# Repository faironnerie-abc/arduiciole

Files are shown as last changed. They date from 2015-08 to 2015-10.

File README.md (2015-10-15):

# What is the "arduiciole" project ?

We try to create some electronic devices, with the ability to flash with an high power led. 
These devices will spread a signal using XBee network, and try to reproduce the 
synchronization phenomena we can observe with fireflies. "arduiciole" is the melt of 
"arduino" and "luciole" (firefly in french).

Each of our arduiciole is tied up to an hellium balloon. We will try to produce between 10 
and 30 of them, for a national science event called "Fête de la science". This show will 
take place in the university library of Le Havre (76, France).

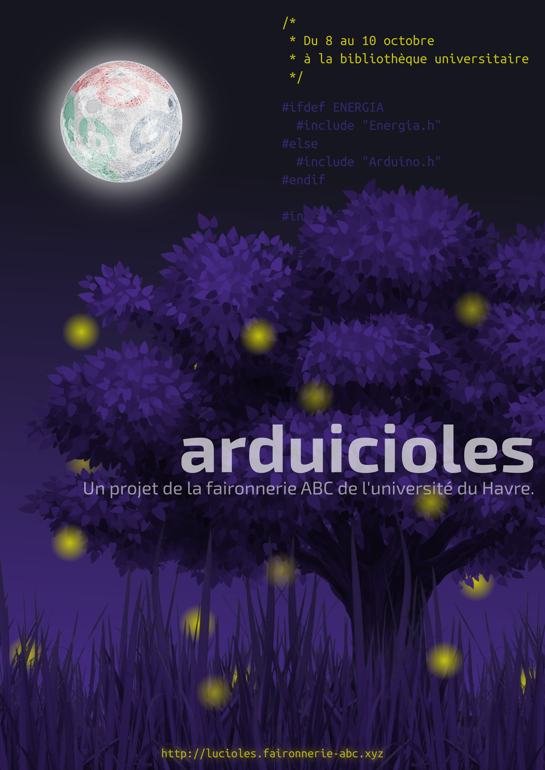
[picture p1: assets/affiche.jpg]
arduiciole case design


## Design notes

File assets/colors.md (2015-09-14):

# Couleurs

* Violet   : #482c8b
* Jaune    : #402c8c
* Fond     : dégradé linéaire, #222222 -> #482c8b
* Lucioles : dégradé radial de l'opacité, #c4c20d
* Textes :
  - Titre               : #efefef
  - Mise en valeur      : #c4c20d
  - Texte de décoration : #402c8c

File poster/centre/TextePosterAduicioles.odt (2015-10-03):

Partagez notre rêve

Nous vous proposons un voyage immobile dans l'atrium de la bibliothèque peuplé de ballons auxquels nos arduicioles sont accrochées. Avec un peu de rêve vous voilà transporté en pleine mangrove où des êtres bizarres rythment le temps avec leurs flashs. Imaginez des arbres de 10 à 12 mètres de hauteur, aux feuillages denses formés de petites feuilles ovales, portant chacune une luciole, toutes les lucioles émettant leur lumière au rythme de trois éclairs toutes les deux secondes, dans un synchronisme parfait, l'obscurité étant totale entre les éclairs. Nous vous invitons de l’autre côté du miroir.

Arduicioles : Petites lucioles électroniques mâles tentant d’échapper à la gravité accrochées à leur ballon, fabriquées à partir de contrôleurs électroniques arduinos couplés à des leds. Ces créatures artificielles sont capables de clignoter en rythme et de se synchroniser toutes ensemble.

Comportement d'une arduiciole :

Chaque luciole va avoir une horloge cyclique et émettre un flash pendant une certaine durée (durée_flash). Après chaque flash il y a un temps de latence pendant lesquelles les lucioles reconstituent les molécules (durée_charge). Chaque luciole perçoit un voisinage, lorsque le nombre de lucioles allumées est supérieur à un seuil et que la période de latence est finie, la luciole tente de se synchroniser en émettant également un flash (horloge:= 0).

Paramètres globaux :

// Même période pour tous

période

// La luciole émet un flash quand son horloge individuelle

// est entre 0 et durée_flash - 1

durée_flash

// Le temps minimum entre 2 flashs

durée_charge

// Nombre de voisins devant être allumés pour déclencher un flash

seuil

//Programme de chaque luciole :

// initialisation aléatoire de l’horloge individuelle

horloge := random(période)

répéter à l'infini {

horloge := horloge + 1

si horloge = période

horloge := 0

si (horloge > durée_flash + durée_charge) et (nombre_voisins_allumés() > seuil)

horloge := 0

si horloge = 0

flash()

si horloge = durée_flash

arrêter_flash()}

}

Dissection d'une arduiciole

Photos

Cycle des arduicioles

ToDo

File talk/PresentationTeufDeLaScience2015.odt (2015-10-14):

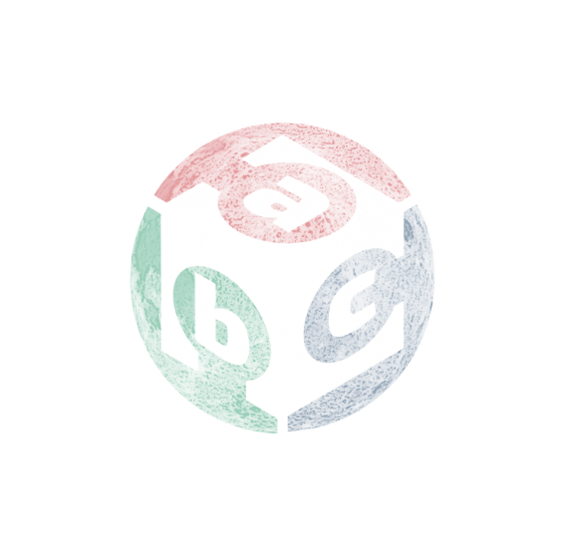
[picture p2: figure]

Arduiciole

Mesdames, messieurs, chers collègues, merci de me donner la parole pour vous présenter la faironnerie ABC et ses arduicioles dans le cadre de la fête de la science. Mais avant de faire un peu de science je vous propose de contextualiser un peu les choses. Ma présentation va se dérouler en 3 temps :

1. Fablab hackerspace et faironnerie
2. Synchronisation
3. Le projet arduiciole

# Fablab hackerspace et faironnerie

## Tiers-lieux

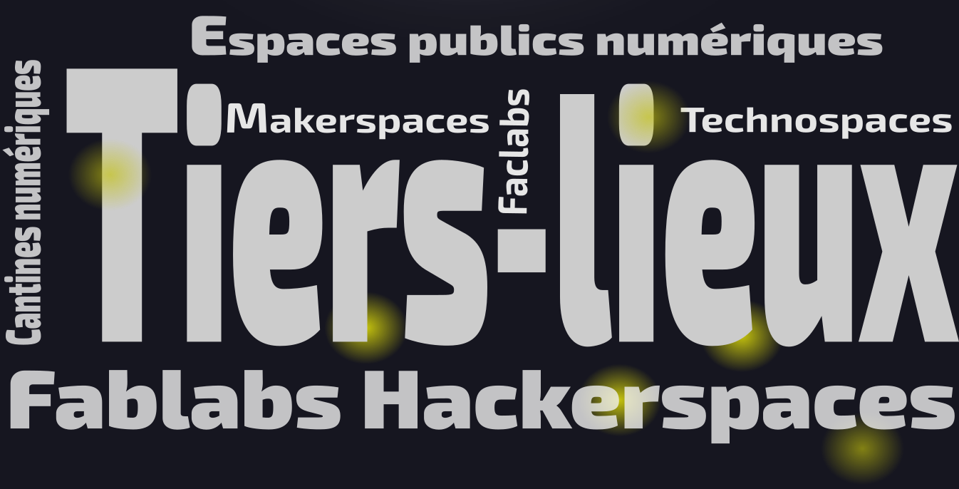
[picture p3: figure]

La novlangue a encore frappé avec ses fablabs, faclabs, techno-spaces, makerspaces et autres hackerspaces ou pour faire plus français les cantines numériques et plus largement les espaces publics numériques. Que ce cache-t-il derrière ces vocables ?

Une réalité contrastée mais avec de nombreux points communs et des objectifs souvent différents. Les différences traduisant souvent des cultures et des origines diverses. Je vous encourage d’ailleurs à ce sujet à aller écouter Michel Lallemand le lundi 1er février à l’UH dans le cadre de l’université populaire sur l’âge du « faire ».

Ces ateliers de fabrication numérique sont souvent décrits comme des tiers-lieux et par l’environnement qu’ils proposent, je ne vais pas déroger à la règle même si cela ne me semble pas le plus important/innovant, mais je reviendrai sur cela dans un second temps.

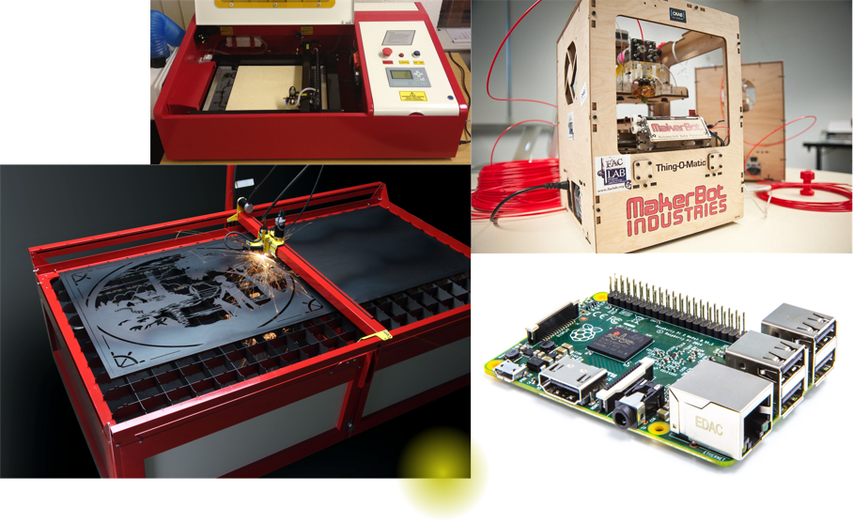
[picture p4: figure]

Ce sont des plate-formes ouvertes de création et de prototypage d’objets physiques, « intelligents » ou non. Elles s’adressent aux entrepreneurs qui veulent passer plus vite du concept au prototype ; aux designers et aux artistes ; aux étudiants désireux d’expérimenter et d’enrichir leurs connaissances pratiques en électronique, en CFAO, en design, en informatique … ; aux bricoliciens du XXIe siècle… On y trouve généralement un univers numérique sans être exhaustif:

1. fraiseuse de précision ;
2. découpeuse laser ;
3. découpe vinyle ;
4. imprimante 3D ;
5. etc.

## Intelligence collective

Ces tiers-lieux se veulent un environnement propice à l’intelligence collective basé sur des interactions, des échanges, des confrontations, du lien et des connaissances partagées. Ce sont de lieux où l’on fait avec la fameuse expression DO IT YOURSELF faites le vous-même à laquelle on devrait préférer DO IT TOGETHER, faites le ensemble ! Le hack transformant, détournant l’objet, le logiciel de son usage premier n’est pas toujours loin. Cela s’appuie sur une éthique que l’on peut résumer de façon imparfaite par :

1. L’accès aux ordinateurs et à tout ce qui pourrait vous apprendre quelque chose sur la façon dont le monde fonctionne devrait être illimité et total Toute information doit être libre.
2. Ne faites pas confiance à l’autorité, préférez la décentralisation. Les systèmes ouverts favorisent l’échange de l’information a contrario de la bureaucratie (Hadopi).
3. Les bricoliciens doivent être jugés sur leurs exploits/réalisations et non sur des critères comme l’âge, l’origine, le sexe, le diplôme, etc. C’est le principe de méritocratie.

Des principes esthétiques sont également mis en avant comme un beau hack, un beau code, un beau montage …. Une forme de lutte y a sa place s’exprimant par exemple par une résistance affirmée à la société de consommation en affirmant une volonté de réutilisabilité, de refus de l’obsolescence, que l’on peut traduire par un slogan « créer plutôt que consommer »

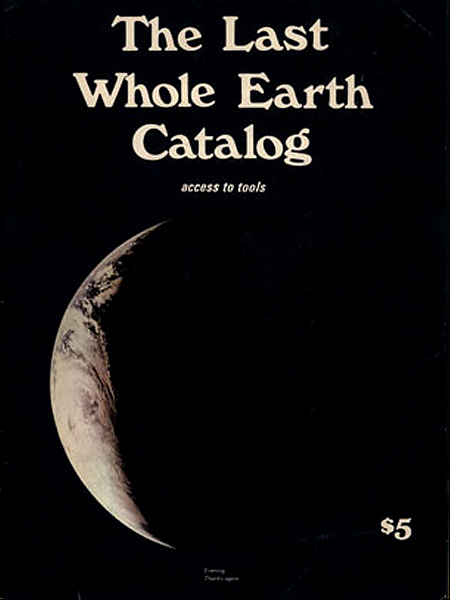
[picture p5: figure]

Source : http://www.openculture.com/2009/01/the_whole_earth_catalog_is_now_online.html

## Des racines profondes

De telles idées existaient déjà sous des formes proches ou d’autres formes que ce soit dans le mouvement ouvrier, hippie ou encore punk et étaient mises en pratique au sein de communauté. J’en veux pour preuve le Whole Earth Truck Store et ensuite le Whole Earth Catalog catalogue américain de contre-culture publié par Stewart Brand entre 1968 et 1972, puis occasionnellement jusqu’en 1998. Ils prônaient déjà le DIY.

## La faironnerie ABC

C’est vous, c’est nous. Au travers du nom, on a voulu mettre en avant le faire mais aussi le côté artisan. La volonté première est d’utiliser cet outil comme médiateur scientifique auprès et avec les étudiants, et de l’ouvrir à un public large. Il sert donc de lien entre enseignement et recherche et est utilisé comme moyen de diffusion de partage et d’échange de la connaissance auprès d’un large public. Cette faironnerie est associée à l’ESADHaR avec une mutualisation des équipements, des ateliers et des formations sans oublier l’association quoi.b et son prolongement alvéole zéro au fort de Tourneville avec un accueil du public hebdomadaire. La bibliothèque universitaire est également partie prenante et elle offre à la fois des locaux, une diffusion d’information auprès d’un public large au-delà de l’université et des programmes culturels dans lesquels les activités de la faironnerie s’intègrent. Le laboratoire de recherche LITIS est lui aussi un acteur important il met à disposition du matériel et des ressources et un environnement informatique. La faironnerie dans sa conception même est réticulaire, cette mise en réseau est faite pour favoriser de nouvelles interactions qui sont une condition nécessaire pour obtenir un écosystème autour du numérique en région tissant ensemble arts, sciences et société, cultures et technologies.

# Synchronisation

Donc, si vous le voulez bien, j’aimerais faire une première expérience avec vous aujourd’hui. Mesdames, messieurs comme je suis un brin cabot vous allez m’applaudir avant la fin de cette présentation.

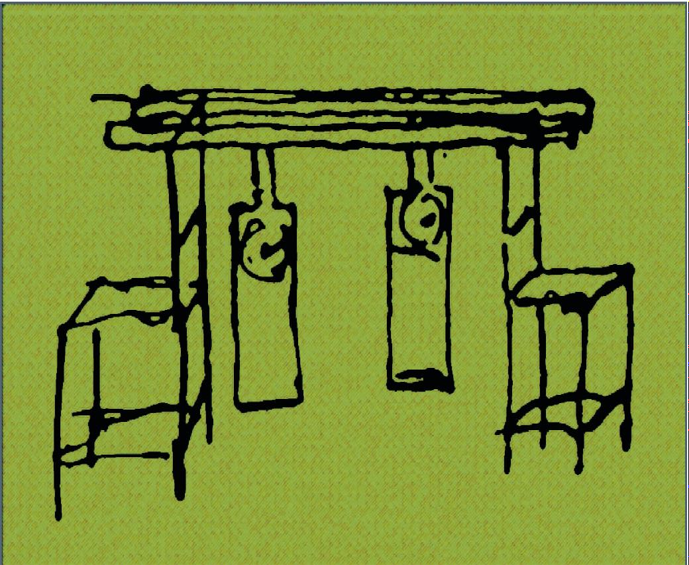
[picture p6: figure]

Dessin original de Huygens sur son expérience avec les horloges. Source : http://www.science-et-vie.com/2015/07/synchronisation-des-horloges-une-enigme-de-350-ans-en-passe-detre-resolue/

Pour une raison que j’ignore, nous prenons du plaisir dans la synchronisation. Nous aimons danser ensemble, nous aimons chanter ensemble. J’ai noté, au fait, que quand vous avez applaudi, vous l’avez fait d’une manière typiquement Française, c’est-à-dire, bruyante et décousue. Vous n’étiez pas organisés. Il ne vous est pas venu à l’idée d’applaudir à l’unisson. Vous pensez que vous pouvez le faire ?

Merci. Je constate que la synchronisation n’a pas de secret pour vous, laissez-moi vous racontez l’histoire de Christiaan Huygens. À la fin de l’hiver 1665, il garda la chambre pendant quelques jours, car il était tombé malade. Sur un mur, il avait accroché côte à côte deux horloges à pendules et, pendant sa convalescence, il remarqua un fait étrange : le mouvement des pendules était synchrone et en opposition de phase, c’est-à-dire que l’un d’eux se balançait vers la gauche quand l’autre allait vers la droite. Quelles que soient leurs positions de départ, au bout d’une demi-heure, les pendules étaient à nouveau en opposition de phase. Huygens devina que cet effet, qu’il nomma sympathie, était dû à d’imperceptibles mouvements que les pendules transmettaient à leur support.

Nous avons des premiers éléments de compréhension : des oscillateurs et un couplage. Un oscillateur à un comportement périodique, il fait en permanence la même chose, comme les métronomes que vous pouvez voir en ce moment. Le couplage (faible), la sympathie devrais je dire, se fait par l’intermédiaire de la planche allez voir le stand du laboratoire de mathématique mes collègues vous expliqueront cela de façon plus rigoureuse. De nombreux exemples naturels existent dans la nature les grillons, mais également nos cellules cardiaques ou encore les lucioles qui émettent des flashs de lumière. Puisque le thème de la fête de la science est la lumière arrêtons nous un instant sur ce phénomène.

# Arduicioles

Chez nos amies les lucioles, l’émission de lumière est provoquée par la réaction entre une protéine la luciférine et une enzyme la luciférase qui catalyse/favorise l’oxydation de la luciférine en présence d’oxygène. Cette oxydation fait passer la luciférine d’un état stable à un état électroniquement excité et instable. En retrouvant son état stable la luciférine émet un photon qui produit une lumière.

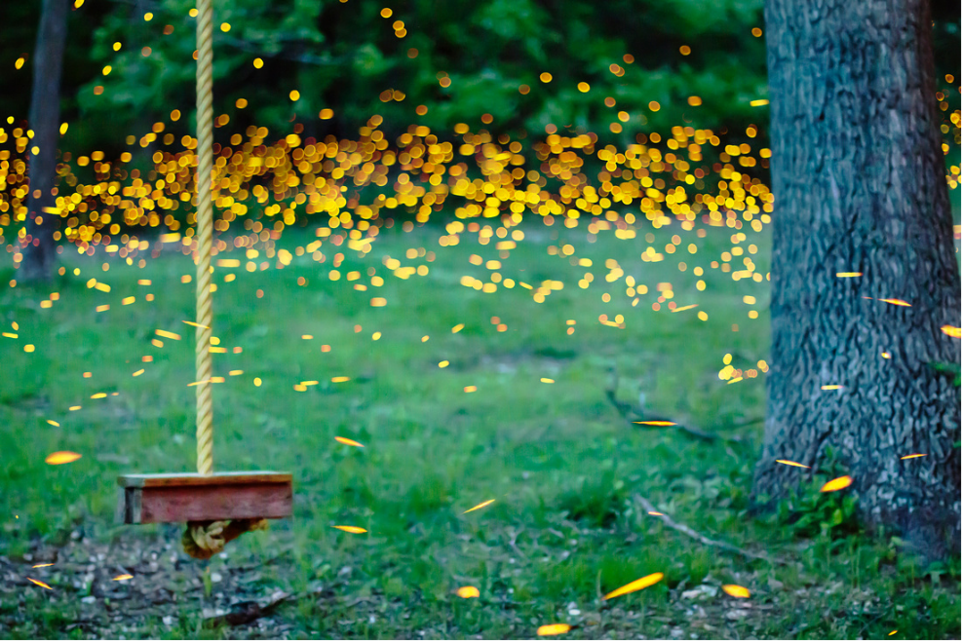
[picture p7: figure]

The fireflies timelaps (Vincent Brady). Source : http://www.vincentbrady.com/fireflies

Je vous fais une proposition de modèle. Chaque luciole va avoir une horloge cyclique et émettre un flash pendant une certaine durée (durée_flash). Après chaque flash il y a un temps de latence pendant lesquelles les lucioles reconstituent les molécules (durée_charge). Chaque luciole perçoit un voisinage, lorsque le nombre de lucioles allumées est supérieur à un seuil et que la période de latence est finie, la luciole tente de se synchroniser en émettant également un flash (horloge:= 0).

Paramètres globaux :

// Même période pour tous

période

// La luciole émet un flash quand son horloge individuelle

// est entre 0 et durée_flash - 1

durée_flash

// Le temps minimum entre 2 flashs

durée_charge

// Nombre de voisins devant être allumés pour déclencher un flash

seuil

//Programme de chaque luciole :

// initialisation aléatoire de l’horloge individuelle

horloge := random(période)

répéter à l’infini {

horloge := horloge + 1

si horloge = période

horloge := 0

si (horloge > durée_flash + durée_charge) et (nombre_voisins_allumés() > seuil)

horloge := 0

si horloge = 0

flash()

si horloge = duree_flash

arrêter_flash()}

}

## Un peu de poésie dans un monde de lucioles, les arduicioles

Je vous propose de voyager avec moi par la pensée jusqu’à l’atrium de la bibliothèque de l’UH. Vous y verrez des arduinos ces petits ordinateurs semblant en lévitation suspendu dans le ciel de la bibliothèque accrochés à des ballons et commandant des leds qui s’allument et s’éteignent. Ils illustrent et transposent nos lucioles en embarquant l’algorithme que je vous ai proposé. Sauront-ils se synchroniser ?

Il ne vous qu’à venir rêver avec nous dans l’atrium de la bibliothèque de l’université du Havre.

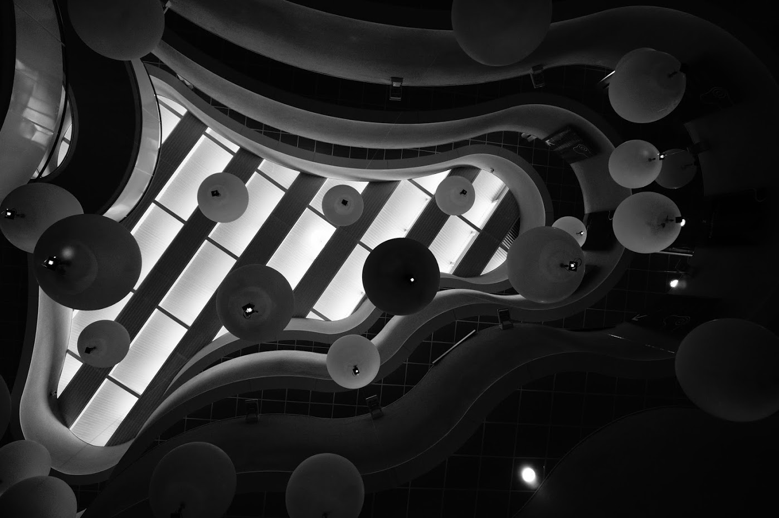
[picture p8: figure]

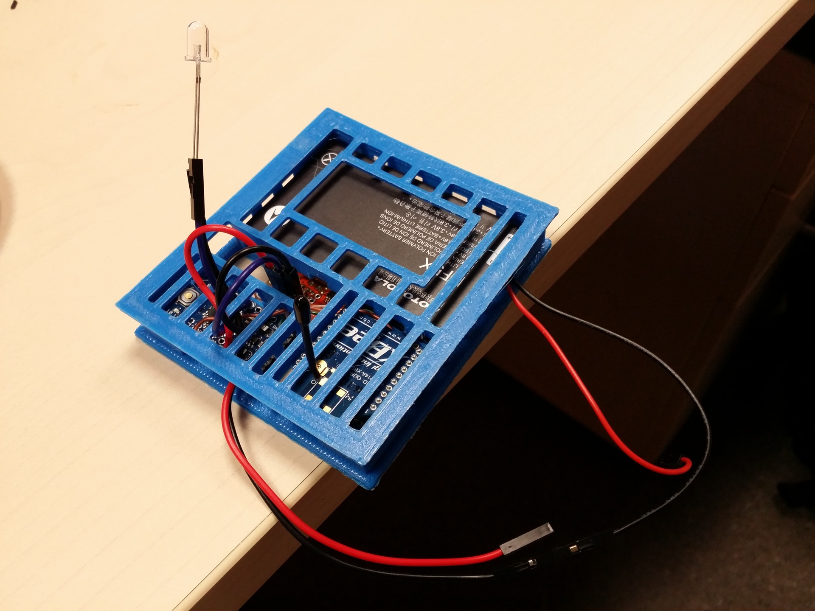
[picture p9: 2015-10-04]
poster/figures/TL_04.jpg

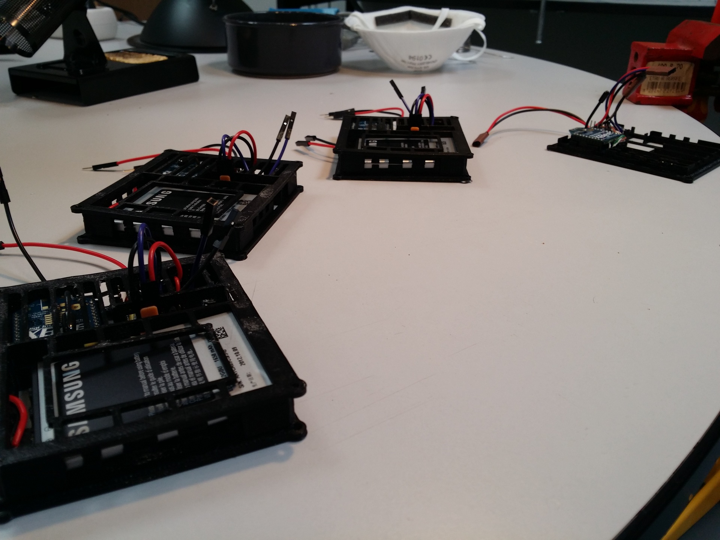
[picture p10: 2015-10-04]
poster/figures/TL_07.jpg

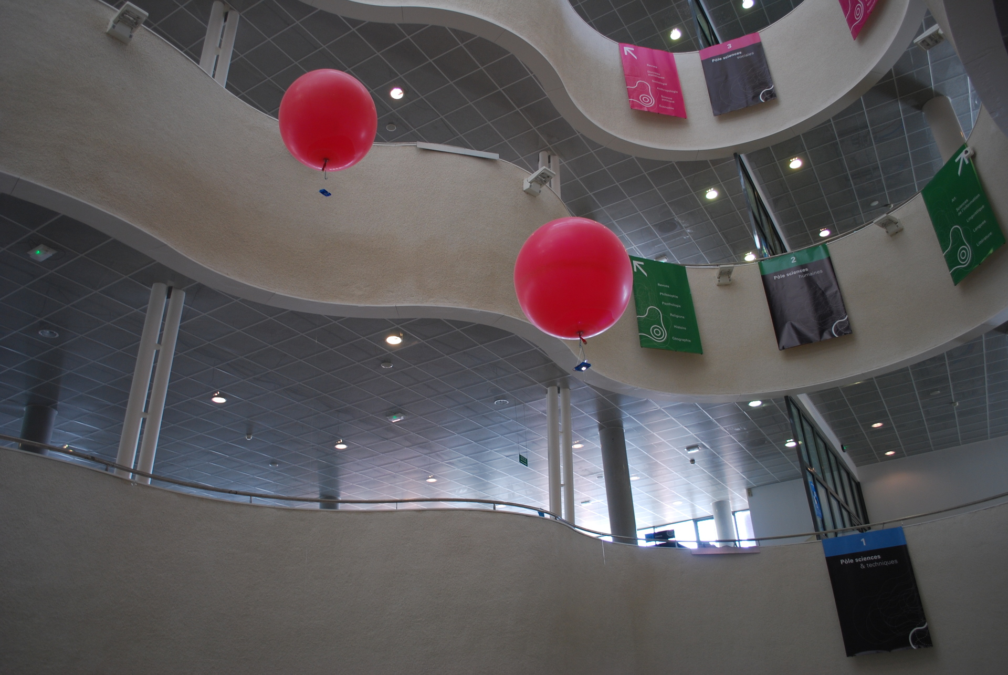
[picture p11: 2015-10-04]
poster/figures/TL_05.jpg

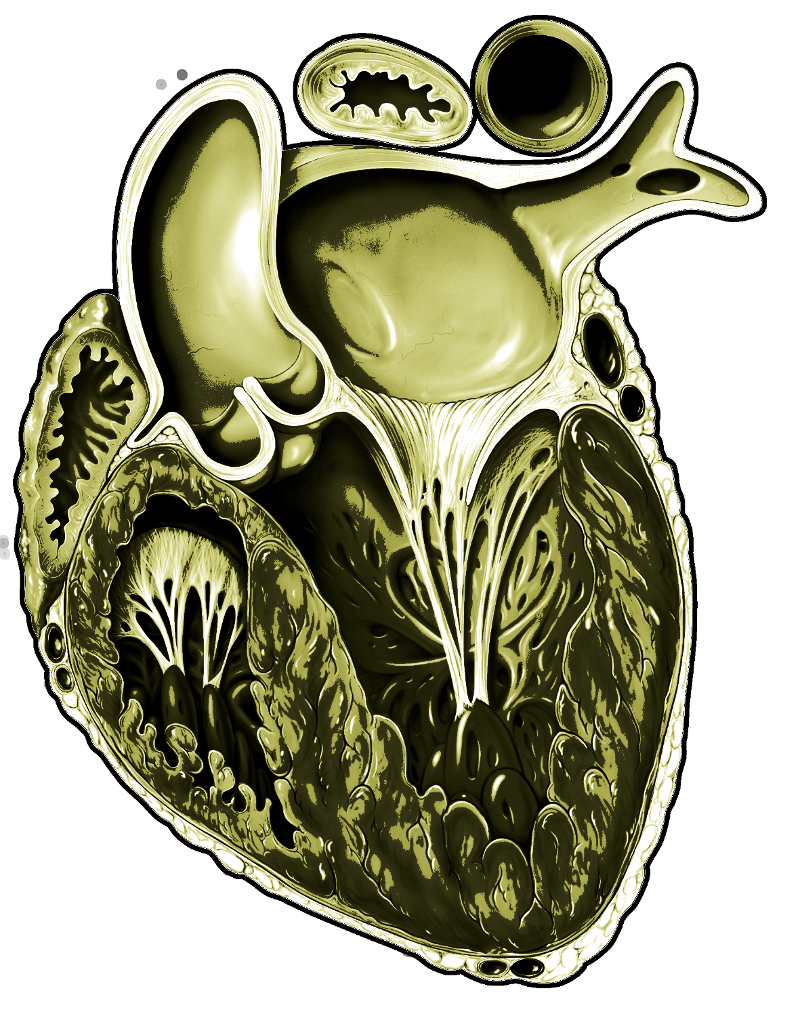
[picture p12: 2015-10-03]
poster/figures/heart.png

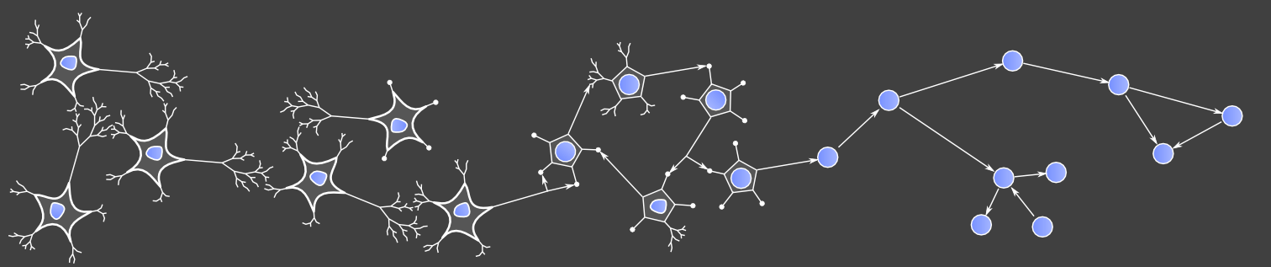
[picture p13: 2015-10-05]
poster/figures/neuron.png

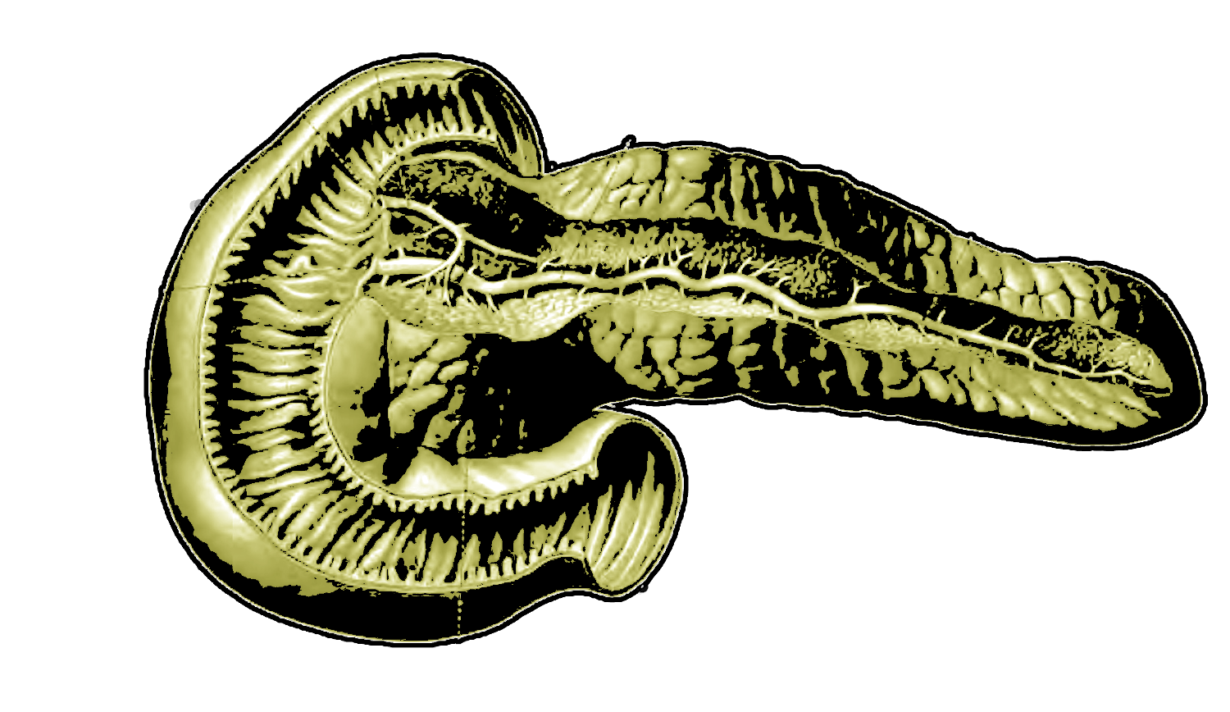
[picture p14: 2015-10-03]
poster/figures/pancreas.png

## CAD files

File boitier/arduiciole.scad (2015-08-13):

/**
 * Copyright (c) 2015 Guilhelm Savin. All rights reserved.
 *
 * This file is part of the ARDUICIOLE project.
 *
 * ARDUICIOLE is free software: you can redistribute it and/or modify
 * it under the terms of the GNU General Public License as published by
 * the Free Software Foundation, either version 3 of the License, or
 * (at your option) any later version.
 *
 * ARDUICIOLE is distributed in the hope that it will be useful,
 * but WITHOUT ANY WARRANTY; without even the implied warranty of
 * MERCHANTABILITY or FITNESS FOR A PARTICULAR PURPOSE.  See the
 * GNU General Public License for more details.
 *
 * You should have received a copy of the GNU General Public License
 * along with ARDUICIOLE.  If not, see <http://www.gnu.org/licenses/>.
 */
include <arduiciole_parts.scad>;

translate([0, 0, 0])
part1();

translate([0, 0, 50])
rotate([0, 180, 0])
part2();

color("green") {
    translate([hled_x, hled_y, 10])
    hled();

    translate([battery_x+sep, battery_y+sep, 30])
    cube([battery_w, battery_h, battery_d]);

    translate([arduino_x+sep, arduino_y+sep, 15])
    cube([arduino_w, arduino_h, arduino_d]);

    translate([0, 0, 20]) {
        translate([xbee_x+sep, xbee_y+sep, 0])
        cube([xbee_support_w, xbee_h, xbee_support_d]);

        translate([xbee_x+5+sep, xbee_y+sep, 8])
        cube([xbee_w-5, xbee_h, xbee_support_d]);

        for (i=[0,xbee_h-2])
        translate([xbee_x+sep+5, xbee_y+sep+i, 2])
        cube([21, 2, 6]);
    }
}

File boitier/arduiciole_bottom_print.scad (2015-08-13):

include <arduiciole_parts.scad>;

part1();

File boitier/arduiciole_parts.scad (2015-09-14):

/**
 * Copyright (c) 2015 Guilhelm Savin. All rights reserved.
 *
 * This file is part of the ARDUICIOLE project.
 *
 * ARDUICIOLE is free software: you can redistribute it and/or modify
 * it under the terms of the GNU General Public License as published by
 * the Free Software Foundation, either version 3 of the License, or
 * (at your option) any later version.
 *
 * ARDUICIOLE is distributed in the hope that it will be useful,
 * but WITHOUT ANY WARRANTY; without even the implied warranty of
 * MERCHANTABILITY or FITNESS FOR A PARTICULAR PURPOSE.  See the
 * GNU General Public License for more details.
 *
 * You should have received a copy of the GNU General Public License
 * along with ARDUICIOLE.  If not, see <http://www.gnu.org/licenses/>.
 */

/*
 * Paramètres de l'imprimante :
 * - extrusion width        : 0.40mm
 * - infill extrusion width : 0.43mm
 * - layer thickness        : 0.25mm
 * - infill                 : 100% (quasiment pas de solide, en dehors des bords. Les rendre plein ne change pas grand chose au poids mais augmente la résistance=
 * - speed                  : 20mm/s
 * - main temp              : 200°C
 * - 1st layer temp         : 205°C
 * - support                : off, mais garde le "raft" en "skirt" pour dégager le surplus dans l'extruder au démarrage.
 */

sep=1;
gap=4;
inter_gap=1.5;
bord=4;

grille_w=1.5;

// Batterie HF5X :
//  battery_w=42;
//  battery_h=66;

// Batterie Samsung :
battery_w=46.25;
battery_h=59+sep+4;
battery_d=5;

arduino_w=18.75;
arduino_h=33.8;
arduino_d=3;

xbee_w=31;
xbee_h=26;
xbee_support_w=28;
xbee_support_d=2;
xbee_d=2;

hled_w=25.5;
hled_h=25.5;

socle=2;
socle_int_w=battery_w+xbee_w+3*sep;
socle_int_h=battery_h+2*sep;
socle_w=socle_int_w+2*bord;
socle_h=socle_int_h+2*bord;
socle_d=2;

delta = 2;
$fn=20;

echo(socle_w, socle_h);

//
// Emplacements.
// (0, 0) est le centre. Les coordonnées sont ceux du coin SW.
//

battery_x=-socle_int_w/2;
battery_y=-socle_int_h/2;

arduino_x=socle_int_w/2-arduino_w-2*sep;
arduino_y=-socle_int_h/2;

xbee_x=socle_int_w/2-xbee_w-2*sep;
xbee_y=socle_int_h/2-xbee_h-2*sep;

hled_x=socle_int_w/2-2*sep-arduino_w-hled_w;
hled_y=socle_int_h/2-xbee_h-2*sep-hled_h;

module bottom() {
    translate([-socle_w/2, -socle_h/2, 0])
    difference() {
        cube([socle_w, socle_h, socle_d]);

        translate([bord, bord, -1])
        cube([socle_int_w, socle_int_h, 7]);
    }
}

//
// Crée le contour d'un rectangle
//

module bb(w, h, d, e=sep) {
    difference() {
        cube([w+2*e, h+2*e, d+socle]);

        translate([e, e, -1])
        cube([w, h, d+socle+2]);
    }
}

module battery_box(inv=false, d=5) {
    union() {
        difference() {
            union() {
                bb(battery_w, battery_h, d);

                //
                // Grille de support
                //

                for (i = [0:13:battery_h-5])
                translate([sep, sep+i, 0])
                cube([battery_w, grille_w, socle_d+(inv?0:2)]);

                if (!inv) {
                  //
                  // Fin de la batterie
                  //

                  translate([sep, sep+59, 0])
                  cube([battery_w, sep, d+socle]);

                  //
                  // Support pour les connecteurs.
                  //
                  union() {
                    translate([sep+7.25, sep+59+sep, 0])
                    cube([3*2.54+1, 4, socle_d+2+1.25]);

                    translate([sep+7.25, sep+59+sep+2.5, socle_d+2])
                    cube([3*2.54+1, 1.5, 1.25+1.25]);
                  }
                }
            }

            //
            // Fentes des connecteurs de la batterie
            //

            if(!inv)
            for (i = [0:3])
            translate([sep+7.25+i*2.54, socle_int_h-7, socle_d+3+1.25])
            cube([1, 9, battery_d]);

            if(inv) {
                //
                // Un peu de place pour les connecteurs de la batterie
                //

                translate([sep+5.5, socle_int_h-2, socle+battery_d-1.5])
                cube([9.5, 6, 5]);

                //
                // Vide pour le trou du couvercle
                //

                translate([2*gap, 2*gap, -1])
                cube([battery_w-4*gap, battery_h-4*gap, d+2]);
            }
        }

        //
        // Trou du couvercle
        //

        if (inv)
        difference() {
            translate([2*gap, sep+2*gap+inter_gap, 0])
            cube([battery_w-4*gap, 8*gap+9*inter_gap, socle_d]);

            translate([2*gap+inter_gap, sep+2*gap+2*inter_gap, -1])
            cube([battery_w-4*gap-2*inter_gap, 8*gap+7*inter_gap, socle_d+2]);
        }
    }
}

module arduino_box(inv=false, d=5) {
    union() {
        bb(arduino_w, arduino_h, d);

        //
        // Grille de support
        //

        difference() {
            union() {
                for (i = [3:12.5:arduino_h-2])
                translate([sep, sep+i, 0])
                cube([arduino_w, grille_w, socle_d+(inv?0:1)]);
            }

            if(!inv) {
                translate([sep, 0, socle_d-0.5])
                cube([3, arduino_h, +3]);
                translate([sep+arduino_w-3, 0, socle_d-0.5])
                cube([3, arduino_h, +3]);
            }
        }
    }
}

module xbee_box(inv=false, d=5) {

    union() {
        bb(xbee_w, xbee_h, d);

        //
        // Grille de support
        //

        translate([sep, sep+4, 0])
        cube([xbee_w, grille_w, socle_d]);

        translate([sep+(inv?0:6+grille_w), sep+xbee_h/2-grille_w/2, 0])
        cube([(inv?xbee_w:xbee_w-6-grille_w), grille_w, socle_d]);

        translate([sep, sep+xbee_h-grille_w-4, 0])
        cube([xbee_w, grille_w, socle_d]);

        //
        // Butée pour le support
        //

        if(!inv) {
            for (i=[4,xbee_h-6])
            translate([sep+xbee_support_w, sep+i, socle_d])
            cube([xbee_w-xbee_support_w, 2, 1.5]);
        }

        //
        // Espace pour les soudures
        //

        if(!inv)
        translate([sep+6, sep+4+grille_w, 0])
        cube([grille_w, xbee_h-8-2*grille_w, socle_d]);
    }
}

module interior(inv=false) {
    difference() {
        //
        // Les différents emplacements
        //

        union() {
            translate([battery_x, battery_y, 0])
            battery_box(inv);

            translate([arduino_x, arduino_y, 0])
            arduino_box(inv);

            translate([xbee_x, xbee_y, 0])
            xbee_box(inv);
        }

        //
        // On enlève un peu de plastique pour alléger et permettre le passage des câbles
        //

        for (i = [10,22, 34, 47, 56])
        translate([-socle_w/2, -socle_h/2+i-2.5, 7-2.5])
        cube([socle_w, 5, 5]);

        for (i = [25, 34, 43, 55, 69, 79])
        translate([-socle_w/2+i-2.5, -socle_h/2, 7-2.5])
        cube([5, , socle_h, 5]);
    }
}

module interior_inv() {
    mirror() {
        interior(true);
    }
}

module hled() {
    union() {
        cube([25,25,2]);

        translate([3, 3, -2])
        cube([19, 19, 2]);

        translate([19, 8.5, 2])
        cube([6, 8, 12]);
    }
}

module part1() {
  difference() {
    union() {
        difference() {
            union() {
                bottom();
                interior();
            }

            //
            // Vide pour la LED puissante
            //

            translate([hled_x, hled_y, -1])
            cube([hled_w, hled_h, 20]);
        }

        //
        // Support de la LED puissante
        //

        translate([hled_x, hled_y, 0]) {
            difference() {
                cube([hled_w, hled_h, 1]);

                translate([3, 3, -1])
                cube([hled_w-6, hled_h-6, 3]);
            }
        }

        //
        // Boucle d'attaches
        //

        for (p = [[-socle_w / 2, -socle_h / 2], [-socle_w / 2, socle_h / 2], [socle_w / 2, -socle_h / 2], [socle_w / 2, socle_h / 2]])
        translate([p.x + (p.x < 0 ? delta : -delta), p.y + (p.y < 0 ? delta : -delta), 0])
        linear_extrude(socle)
        circle(3);
    }

    for (p = [[-socle_w / 2, -socle_h / 2], [-socle_w / 2, socle_h / 2], [socle_w / 2, -socle_h / 2], [socle_w / 2, socle_h / 2]])
    translate([p.x + (p.x < 0 ? delta : -delta), p.y + (p.y < 0 ? delta : -delta), -1])
    linear_extrude(socle+2)
    circle(1.5);
  }
}

module part2() {
    translate([-socle_w/2, -socle_h/2, 0])
    difference() {
        union() {
            difference() {
                cube([socle_w, socle_h, socle_d]);

                translate([bord, bord, -1])
                cube([socle_int_w, socle_int_h, socle_d+2]);
            }

            translate([bord/2, bord/2, socle_d])
            difference() {
                //
                // Matière première pour les bords
                //

                cube([socle_w-bord, socle_h-bord, 10]);

                //
                // On vide l'intérieur
                //
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

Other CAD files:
boitier/arduiciole_print.scad
boitier/arduiciole_print_x2.scad

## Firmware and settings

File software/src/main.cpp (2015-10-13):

/**
 * Copyright (c) 2015 Guilhelm Savin. All rights reserved.
 *
 * This file is part of the ARDUICIOLE project.
 *
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
 * You should have received a copy of the GNU General Public License
 * along with ARDUICIOLE.  If not, see <http://www.gnu.org/licenses/>.
 */

#include "arduiciole.h"

#ifdef DEBUG
#include <AltSoftSerial.h>
AltSoftSerial altSoftSerial;
#endif

cmd_t message = CMD_SYNC;
luciole_t state;

unsigned long cycle_length = LUCIOLE_FLASH_PHASE_LENGTH + LUCIOLE_WAIT_PHASE_LENGTH + LUCIOLE_ADJUST_BASE_DELAY;

/*
 * @see arduiciole.h#error_mode
 */
void error_mode(uint8_t error) {
  while (1) {
    HELPER_BLINK(CLED, 300, error);
    delay(1000);
  }
}

/*
 * @see arduiciole.h#listen()
 */
void listen(unsigned long time_out) {
  unsigned long clock = millis(), clock2;
  uint8_t cmd;
  uint8_t *data;

  while (millis() < clock + time_out) {
    cmd = xbee_receive(max(1, time_out - (millis() - clock)), &data);

    if (cmd != CMD_NONE) {
        switch(cmd) {
        case CMD_SYNC:
          /*
           * On cherche à déterminer le décalage entre le début du cycle de cette
           * luciole, et le début de celle dont on vient de recevoir le SYNC.
           * Pour prendre en compte la latence liée au réseau, on soustrait
           * la valeur LUCIOLE_ADJUST_ESTIMATE_MEAN_TX_DELAY au délai déterminé.
           * Cependant, si le paquet est réçu alors que la luciole est à une
           * distance temporelle inférieure à LUCIOLE_ADJUST_ESTIMATE_MEAN_TX_DELAY,
           * il faut considérer que le paquet a été envoyé à la fin du cycle précédent
           * et adapter notre calcul en conséquence relativement à `cycle_length`.
           */
          clock2 = millis() - state.start_at;
          clock2 = clock2 + cycle_length - LUCIOLE_ADJUST_ESTIMATE_MEAN_TX_DELAY;
          clock2 = clock2 % cycle_length;

#ifdef DEBUG
          altSoftSerial.print("[CMD] SYNC @ ");
          altSoftSerial.print(millis() - state.start_at);
          altSoftSerial.print(" | REMOTE CLOCK ");
          altSoftSerial.println(clock2);
#endif
          state.swarm_cumul += clock2;
          state.swarm_size  += 1;

          break;
        case CMD_RESET:
          delay(random(LUCIOLE_RESET_MIN_DELAY, LUCIOLE_RESET_MAX_DELAY));

          DEBUG_PRINT("[CMD] RESET")

          break;
        case CMD_EPSILON:
          state.epsilon = data[1] / 255.0;

          DEBUG_PRINT_VAL("[SET] EPSILON = ", state.epsilon)

          break;
        case CMD_ON:
          state.enabled = LUCIOLE_ON;

          DEBUG_PRINT("[SET] ENABLED ON")

          break;
        case CMD_OFF:
          state.enabled = LUCIOLE_OFF;

          DEBUG_PRINT("[SET] ENABLED OFF")

          break;
        case CMD_TX_STATUS:
          DEBUG_PRINT_VAL("[CMD] TX STATUS @ ", millis() - state.start_at)

          break;
        }
  	}
  }
}

/*
 * @see arduiciole.h#flash
 */
void flash() {
  //
  // Dawn
  //

  xbee_transmit();

  for (int i=0; i<=255; i++)
    HELPER_ANALOG_WRITE(i, 1);
  HELPER_DIGITAL_WRITE(HIGH, 0);

  listen(LUCIOLE_FLASH_LENGTH - min(LUCIOLE_FLASH_LENGTH, millis() - state.start_at + 255));

  //
  // Twilight
  //

  for (int i=255; i>=0; i--)
    HELPER_ANALOG_WRITE(i, 1);
  HELPER_DIGITAL_WRITE(LOW, 0);
}

/*
 * @see arduiciole.h#sync()
 */
void sync() {
  //
  // Le cycle de la luciole, sans la période d'ajustement, doit
  // durer LUCIOLE_FLASH_PHASE_LENGTH + LUCIOLE_WAIT_PHASE_LENGTH ms.
  // On attend donc le temps restant, en lisant les paquets.
  //

  long until = state.start_at + LUCIOLE_FLASH_PHASE_LENGTH + LUCIOLE_WAIT_PHASE_LENGTH;
  until -= millis();

  listen (max(1, until));
}

/*
 * @see arduiciole.h#adjust()
 */
void adjust() {
  unsigned long adjust_delay = LUCIOLE_ADJUST_BASE_DELAY;

  if (state.swarm_size) {
    unsigned long mean = state.swarm_cumul / state.swarm_size;
    long d;

    if (mean < cycle_length / 2) {
      d = mean;
    }
    else {
      d = cycle_length / 2 - mean;
    }

    DEBUG_PRINT_VAL("[ADJ] mean = ", mean)
    DEBUG_PRINT_VAL("      half = ", cycle_length / 2)
    DEBUG_PRINT_VAL("      d    = ", d)
    
    //
    // Atténuation pour augmenter la durée nécessaire à la synchro.
    //

    d = round(state.epsilon * d);

    d = max(-LUCIOLE_ADJUST_BASE_DELAY, d);
    d = min( LUCIOLE_ADJUST_BASE_DELAY, d);

    DEBUG_PRINT_VAL("[ADJ] Délai d'ajustement ", d)

    adjust_delay += d;
  }

  state.swarm_cumul = 0;
  state.swarm_size  = 0;

  listen(adjust_delay);
}

/**
 * Initialisation de l'Arduino.
 *
 * Le port série est ouvert pour permettre la communication avec le module XBee,
 * puis ce dernier est configuré.
 */
void setup() {
#ifdef DEBUG
  altSoftSerial.begin(9600);
#endif

  pinMode(CLED, OUTPUT);

  HELPER_BLINK(CLED, 150, 5);

  pinMode(HLED, OUTPUT);
  pinMode(LLED, OUTPUT);

#ifdef DEBUG
  //
  // LEDs de débogage.
  //

  pinMode(6, OUTPUT);
  pinMode(7, OUTPUT);
  pinMode(11, OUTPUT);
#endif

  //
  // Initialisation de l'état de la luciole
  //

  state.start_at = 0;
  state.swarm_cumul = 0;
  state.swarm_size = 0;
  state.epsilon = LUCIOLE_ADJUST_EPSILON;
  state.enabled = LUCIOLE_ON;

  //
  // XBee initialization
  //

  xbee_init(&message);
}

/**
 * Boucle principale de l'Arduino.
 */
void loop() {
  if (state.enabled == LUCIOLE_ON) {
    state.start_at = millis();

    //
    // Émission de lumière.
    // Bon ok, plus d'électrons que de photons...
    //

    flash();

    //
    // Diffusion de l'adresse si besoin.
    //

    xbee_spread();

    //
    // Phase de synchronisation.
    //

    sync();

    //
    // Phase d'ajustement.
    //

    adjust();
  }
  else {
    listen(1000);
  }
}

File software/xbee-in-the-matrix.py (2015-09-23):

# -*- coding: utf-8 -*-

import serial, sys, socket, random
from threading import Lock
from time import sleep
from xbee import ZigBee
from struct import Struct

DELAY = 50
FLASH_LENGTH = 20

LUCIOLE_HUE        = 60
LUCIOLE_SATURATION = 0.9
LUCIOLE_COUNT      = 30
LUCIOLE_VIEW       = 3

MATRIX_IP     = "10.4.40.223"
MATRIX_PORT   = 6038
MATRIX_FOOTER = ''.join(chr(0x00) for x in range(0, 362+3*20))
MATRIX_HEADER = ''.join(chr(x)    for x in [
	0x04, 0x01, 0xdc, 0x4a,
	0x01, 0x00,
	0x08, 0x01,
	0x00, 0x00, 0x00, 0x00,
	0xff, 0xff, 0xff, 0xff,
	0x01,
	0x00,
	0x00, 0x00,
	0x00, 0x02,
	0x00, 0x00
])

SERIAL_PORT     = "/dev/ttyAMA0"
#SERIAL_PORT     = "/dev/ttyUSB0"
SERIAL_BAUDRATE = 9600

LOCK = Lock()

STRUCT_ADDR = Struct("<H")
STRUCT_MSG  = Struct("<BL")

CMD_SYNC  = 0x01
CMD_RESET = 0x02

SIMULATION = True

def hsv2rgb(h, s, v):
	c = s * v
	p = h / 60
	x = c * ( 1 - abs((p % 2) - 1))
	m = v - c

	r = 0
	v = 0
	b = 0

	if (p < 1):
		r = c
		v = x
	elif (p < 2):
		r = x
		v = c
	elif (p < 3):
		v = c
		b = x
	elif (p < 4):
		v = x
		b = c
	elif (p < 5):
		r = x
		b = c
	else:
		r = c
		b = x

	r = chr(int(255 * (r + m)))
	v = chr(int(255 * (v + m)))
	b = chr(int(255 * (b + m)))

	return (r, v, b)

def get_color(step):
	if not step:
		return (chr(0), chr(0), chr(0))
	else:
		return hsv2rgb(LUCIOLE_HUE, LUCIOLE_SATURATION, 1 - abs(step - FLASH_LENGTH / 2.0) / (FLASH_LENGTH / 2.0))

counter = 1

def update_lucioles(lucioles):
	if SIMULATION:
		update_lucioles_simulation(lucioles)
	else:
		for l in lucioles:
			luciole_step(l)

def update_lucioles_simulation(lucioles):
	global counter

	for l in lucioles:
		l['next_step'] = LUCIOLE_VIEW * l['step']
		luciole_step(l)

		if counter == 0:
			for j in range(1, LUCIOLE_VIEW+1):
				l['next_step'] += lucioles[(l['id']+j)%len(lucioles)]['step']
			l['next_step'] /= 2 * LUCIOLE_VIEW
			
	if counter == 0:
		for l in lucioles:
			l['step'] = l['step'] - int((l['step'] - l['next_step']) * 0.4)

	counter = (counter + 1) % 100

def luciole_step(l):
	l['step'] = (l['step'] + 1) % 100

	if l['step'] == 0:
		l['flash_step'] = 1
	elif l['flash_step']:
		l['flash_step'] = (l['flash_step'] + 1) % FLASH_LENGTH
		l['rvb']        = get_color(l['flash_step'])

if __name__ == "__main__":
	ser      = serial.Serial(SERIAL_PORT, SERIAL_BAUDRATE)
	sock     = socket.socket(socket.AF_INET, socket.SOCK_DGRAM)
	lucioles = [{'id': i, 'step': int(random.random() * 100), 'flash_step': 0, 'rvb': ('\x00', '\x00', '\x00')} for i in range(0, LUCIOLE_COUNT)]
	lucioles_addr = {}

	def handle_frame(data):
		"""
		Callback appelé lors de la réception d'une frame par le XBee.
		"""
		if data['id'] == 'rx':
			addr = STRUCT_ADDR.unpack(data['source_addr'])[0]
			msg  = STRUCT_MSG.unpack(data['rf_data'])

			if addr not in lucioles_addr:
				lucioles_addr[addr] = len(lucioles_addr)
				print "Nouvelle luciole %d -> %d" % (addr, lucioles_addr[addr])

			if msg[0] == CMD_SYNC:
				with LOCK:
					lucioles[lucioles_addr[addr]]['flash_step'] = 1

	xbee = ZigBee(ser, callback=handle_frame, escaped=True)

	while True:
		with LOCK:
			update_lucioles(lucioles)

		states = ''.join(l['rvb'][0] + l['rvb'][1] + l['rvb'][2] for l in lucioles)
		sock.sendto(MATRIX_HEADER + states + MATRIX_FOOTER, (MATRIX_IP, MATRIX_PORT))

		try:
			sleep(DELAY / 1000.0)
		except KeyboardInterrupt:
			break

	xbee.halt()
	ser.close()

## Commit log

2015-08-13 Update box and add software sources
    [arduiciole_bottom_print.scad, arduiciole_parts.scad]
2015-08-13 Just add a licence for fun
    [arduiciole.scad, arduiciole_parts.scad, arduiciole_print.scad]
2015-09-14 Amélioration du modèle de boitier
    [arduiciole_parts.scad]
2015-09-14 Ajout des versions PNG des images.
2015-09-14 Ajout de l'affiche en différents formats.
2015-09-14 Déplacements des images.
2015-09-14 Déplacement de l'affiche dans assets/
2015-09-14 Mise à jour des images
2015-09-24 Un peu de propre dans le code
2015-09-24 Déplacement des fichiers openscad dans le dossier boitier/
    [arduiciole.scad, arduiciole_bottom_print.scad, arduiciole_parts.scad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]
2015-09-25 Ajout de la liste des XBee
2015-09-29 Mise à jour des partenaires
2015-10-02 Poster du centre - cycle des arduicioles
2015-10-03 Deplacement de quelques cartouches
2015-10-04 Harmonisation des posters
2015-10-05 Versions finales des posters
2015-10-05 Tentative de réduction du broadcast
2015-10-06 Ajout de documentation
2015-10-15 Changement de l'image du README
